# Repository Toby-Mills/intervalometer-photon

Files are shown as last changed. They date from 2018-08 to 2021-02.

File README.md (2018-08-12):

# intervalometer-photon

A Particle project named intervalometer-photon

## Welcome to your project!

Every new Particle project is composed of 3 important elements that you'll see have been created in your project directory for intervalometer-photon.

#### ```/src``` folder:  
This is the source folder that contains the firmware files for your project. It should *not* be renamed. 
Anything that is in this folder when you compile your project will be sent to our compile service and compiled into a firmware binary for the Particle device that you have targeted.

If your application contains multiple files, they should all be included in the `src` folder. If your firmware depends on Particle libraries, those dependencies are specified in the `project.properties` file referenced below.

#### ```.ino``` file:
This file is the firmware that will run as the primary application on your Particle device. It contains a `setup()` and `loop()` function, and can be written in Wiring or C/C++. For more information about using the Particle firmware API to create firmware for your Particle device, refer to the [Firmware Reference](https://docs.particle.io/reference/firmware/) section of the Particle documentation.

#### ```project.properties``` file:  
This is the file that specifies the name and version number of the libraries that your project depends on. Dependencies are added automatically to your `project.properties` file when you add a library to a project using the `particle library add` command in the CLI or add a library in the Desktop IDE.

## Adding additional files to your project

#### Projects with multiple sources
If you would like add additional files to your application, they should be added to the `/src` folder. All files in the `/src` folder will be sent to the Particle Cloud to produce a compiled binary.

#### Projects with external libraries
If your project includes a library that has not been registered in the Particle libraries system, you should create a new folder named `/lib/<libraryname>/src` under `/<project dir>` and add the `.h` and `.cpp` files for your library there. All contents of the `/lib` folder and subfolders will also be sent to the Cloud for compilation.

## Compiling your project

When you're ready to compile your project, make sure you have the correct Particle device target selected and run `particle compile <platform>` in the CLI or click the Compile button in the Desktop IDE. The following files in your project folder will be sent to the compile service:

- Everything in the `/src` folder, including your `.ino` application file
- The `project.properties` file for your project
- Any libraries stored under `lib/<libraryname>/src`

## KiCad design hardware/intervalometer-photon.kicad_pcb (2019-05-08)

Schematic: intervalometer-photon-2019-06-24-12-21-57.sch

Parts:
D1: LED; LED_D5.0mm
J3: Conn_01x02; TerminalBlock_bornier-2_P5.08mm
R1: R; R_Axial_DIN0207_L6.3mm_D2.5mm_P7.62mm_Horizontal
SW1: SW_DIP_x01; TerminalBlock_bornier-2_P5.08mm
U1: LTV-827; DIP-8_W7.62mm
U2: Photon; photon_tht

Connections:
3V3: U2.24
GND: D1.1, SW1.1, U2.21
unnamed: D1.2, U1.2
unnamed: J3.1, U1.8
unnamed: J3.2, U1.7
unnamed: R1.1, U1.1
OPTO: R1.2, U2.14
START: SW1.2, U2.19

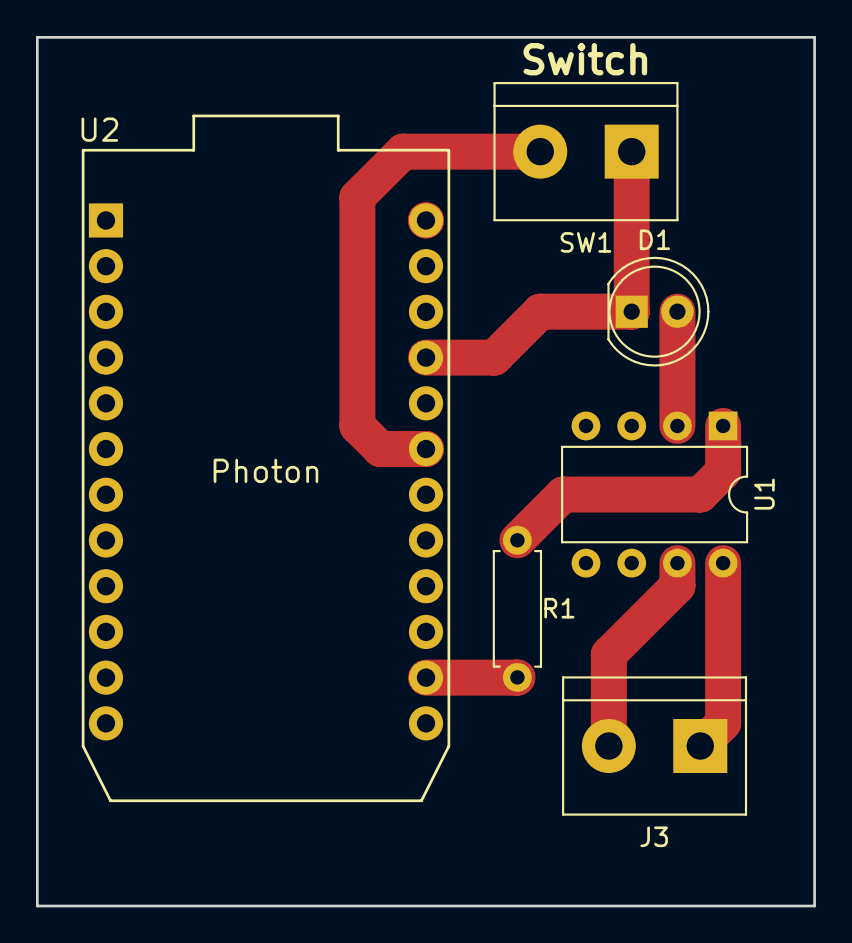
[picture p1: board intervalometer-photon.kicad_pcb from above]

Board: 2 copper layers, 43.2 x 48.3 mm, 6 parts (0 on the bottom side), 7 nets.

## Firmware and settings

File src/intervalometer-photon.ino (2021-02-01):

#include "config.h" //add your own config.h with: char const blynkToken[] = "your-blynk-token-here";
#include "blynk.h"
//--------------------------------------------------------------
// System Configuration
//--------------------------------------------------------------
SYSTEM_THREAD(ENABLED); //enables system functions to happen in a separate thread from the application setup and loop
//this includes connecting to the network and the cloud

//--------------------------------------------------------------
// Pins
//--------------------------------------------------------------
int shutterPin = D1;
int LEDPin = D7;
int switchPin = D6;

//--------------------------------------------------------------
// Blynk Pins
//--------------------------------------------------------------
int blynkPinMessage = 0;
int blynkPinStart = 1;
int blynkPinInterval = 2;
int blynkPinExposure = 3;
int blynkPinMirrorLockup = 4;
int blynkPinBlackFrame = 5;
int blynkPinBracketExposure = 6;

//--------------------------------------------------------------
// User Settings
//--------------------------------------------------------------
int photoIntervalSeconds = 30;
bool mirrorLockupDelay = true;
bool blackFrameEnabled = true;
int exposureLengthMillis = 10000;
int bracketExposureLengthMillis = 0;
bool started = false;

//--------------------------------------------------------------
// Internal Variables
//--------------------------------------------------------------
//enums
enum ExposureBracketShot {UnderExposed, Exposed, OverExposed};
enum PhotoPhase {None = 0, MirrorLockupDelay = 1, MirrorLockupBuffer = 2, Exposure = 3, BlackFrameDelay = 4, Processing = 5};

// internal variables
bool connectedOnce = false;
int debugTimeout = 0;

PhotoPhase currentPhase = None;
int lastPhotoStartTime = 0;
int currentPhaseStartTime = 0;
ExposureBracketShot currentBracketShot = Exposed;
int currentBracketExposureDuration = 0;
int mirrorLockupDuration = 500;
int mirrorLockupBuffer = 1000;
int processingDuration = 300;

char *sourceCode =  "https://github.com/Toby-Mills/intervalometer-photon";

//---------------------------------------------------------------
// Functions
//---------------------------------------------------------------
void start(){
  started = true;
}

void end(){
  started = false;
  setShutter(LOW);
}

void setPhase(PhotoPhase value){
  //char msg [50];
  //sprintf(msg, "set phase %d", value);
  //debugMessage("set phase", msg);
  currentPhase = value;
  currentPhaseStartTime = -1; //indicates that the phase has not started yet
}

bool phaseStarted(){
  return currentPhaseStartTime > -1;
}

void startPhase(){
  currentPhaseStartTime = millis();
}

int phaseElapsedTime(){
  return millis() - currentPhaseStartTime;
}

void setShutter(int value){
  digitalWrite(shutterPin, value);
  digitalWrite(LEDPin, value);
}

bool debugging(){
  return millis() < debugTimeout;
}

int startDebugging(String duration){
  debugTimeout = millis() + duration.toFloat();
  debugMessage("DebugStart","");
  return duration.toFloat();
}

bool userMessage(String message){
  return Particle.publish("message", message);
  Blynk.virtualWrite(0, message);
}

bool debugMessage(String eventName, String data){
  if (debugging()){
    return Particle.publish(eventName, data);
  }
}

//--------------------------------------------------------------
// Setup
//--------------------------------------------------------------

// setup() runs once, when the device is first turned on.
void setup() {
  // Put initialization like pinMode and begin functions here.
  pinMode(shutterPin, OUTPUT);
  pinMode(LEDPin, OUTPUT);
  pinMode(switchPin, INPUT_PULLDOWN);
  
  Particle.variable("sourceCode", sourceCode, STRING);
  Particle.variable("interval", photoIntervalSeconds);
  Particle.variable("lockup", mirrorLockupDelay);
  Particle.variable("blackFrame", blackFrameEnabled);
  Particle.variable("exposure", exposureLengthMillis);
  Particle.variable("bracket", bracketExposureLengthMillis);
  Particle.variable("phaseStart", currentPhaseStartTime);
  Particle.variable("phase", currentPhase);
  Particle.variable("lastPhoto", lastPhotoStartTime);
  Particle.variable("phase", currentPhase);
  Particle.function("startDebug", startDebugging);

  Blynk.begin(blynkToken); //Create connection to Blynk Cloud
  updateBlynkPins(); //update Blynk variables
}

//--------------------------------------------------------------
// Loop
//--------------------------------------------------------------

// loop() runs over and over again, as quickly as it can execute.
void loop() {
  Blynk.run(); //read / write Blynk pins

  //if(digitalRead(switchPin) == HIGH){
  //  start();
  //}else{
  //  end();
  //}

  if(started){
    switch(currentPhase){
      case None:
        if(millis() - lastPhotoStartTime >= photoIntervalSeconds * 1000){
          lastPhotoStartTime = millis();
          if (bracketExposureLengthMillis > 0){
            currentBracketShot = UnderExposed;
          }
          setPhase(MirrorLockupDelay);
        }
        break;
      case MirrorLockupDelay:
        if (mirrorLockupDelay){
          if (phaseStarted()){
            if (phaseElapsedTime() >= mirrorLockupDuration){
              setShutter(LOW);
              setPhase(MirrorLockupBuffer);
            }
          }else{
              startPhase();
              setShutter(HIGH);
          }
        }else{
          setPhase(Exposure);
        }
        break;

      case MirrorLockupBuffer:
          if (mirrorLockupDuration > 0){
            if (phaseStarted()){
              if (phaseElapsedTime() >= mirrorLockupBuffer){
                setPhase(Exposure);
              }
            }else{
              startPhase();
            }
          }else{
            setPhase(Exposure);
          }
        break;

      case Exposure:
        if (phaseStarted()){
          if (phaseElapsedTime() >= currentBracketExposureDuration){
            setShutter(LOW);
            setPhase(BlackFrameDelay);
          }
        }else{
          startPhase();
          switch (currentBracketShot) {
            case UnderExposed:
              currentBracketExposureDuration = exposureLengthMillis - bracketExposureLengthMillis;
              break;
            case Exposed:
              currentBracketExposureDuration = exposureLengthMillis;
              break;
            case OverExposed:
              currentBracketExposureDuration = exposureLengthMillis + bracketExposureLengthMillis;
              break;
          }
          setShutter(HIGH);
        }
        break;

      case BlackFrameDelay:
        if (blackFrameEnabled){
          if (phaseStarted()){
            if (phaseElapsedTime() >= currentBracketExposureDuration){
              setPhase(Processing);
            }
          }else{
            startPhase();
          }
        }else{
          setPhase(Processing);
        }
        break;

      case Processing:
        if (phaseStarted()){
          if (phaseElapsedTime() >= processingDuration){
            if (bracketExposureLengthMillis == 0){
              setPhase(None);
            }else{
              switch(currentBracketShot){
                case UnderExposed:
                  currentBracketShot = Exposed;
                  setPhase(MirrorLockupDelay);
                  break;
                case Exposed:
                  currentBracketShot = OverExposed;
                  setPhase(MirrorLockupDelay);
                  break;
                case OverExposed:
                  setPhase(None);
                  break;
              }
            }
          }
        }else{
          startPhase();
        }
        break;
    }
  }
}

//--------------------------------------------------------------
// Blynk methods
//--------------------------------------------------------------

BLYNK_WRITE(V1)
{
  int pinValue = param.asInt();
  char value[] = "";
  sprintf(value, "%d", pinValue);
  debugMessage("BlynkSetStart", value);
  if (pinValue == 1){start();};
  if (pinValue == 0){end();};
}
BLYNK_WRITE(V2)
{
  int pinValue = param.asInt();
  char value[] = "";
  sprintf(value, "%d", pinValue);
  debugMessage("BlynkSetInterval", value);
  photoIntervalSeconds = pinValue;
}
BLYNK_WRITE(V3)
{
  float pinValue = param.asFloat();
  char value[] = "";
  sprintf(value,"%f", pinValue);
  debugMessage("BlynkSetExposure", value);
  exposureLengthMillis = pinValue * 1000;
}
BLYNK_WRITE(V4)
{
  int pinValue = param.asInt();
  char value[] = "";
  sprintf(value, "%d", pinValue);
  debugMessage("BlynkSetLockup", value);
  mirrorLockupDelay = (pinValue == 1);
}
BLYNK_WRITE(V5)
{
  int pinValue = param.asInt();
  char value[] = "";
  sprintf(value, "%d", pinValue);
  debugMessage("BlynkSetBlackFrame", value);
  blackFrameEnabled = (pinValue == 1);
}
BLYNK_WRITE(V6)
{
  float pinValue = param.asFloat();
  char value[] = "";
  sprintf(value,"%f", pinValue);
  debugMessage("BlynkSetBracket", value);
  bracketExposureLengthMillis = pinValue * 1000;
}

void updateBlynkPins(){
  int blynkPinInterval = 2;
  if(started){
    Blynk.virtualWrite(blynkPinStart, 1);
  }else{
    Blynk.virtualWrite(blynkPinStart,0);
  }
  Blynk.virtualWrite(blynkPinInterval, photoIntervalSeconds);
  Blynk.virtualWrite(blynkPinExposure, exposureLengthMillis / 1000);
  Blynk.virtualWrite(blynkPinMirrorLockup, (mirrorLockupDelay == true));
  Blynk.virtualWrite(blynkPinBlackFrame, (blackFrameEnabled == true));
  Blynk.virtualWrite(blynkPinBracketExposure, bracketExposureLengthMillis / 1000);
}

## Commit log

2018-08-15 Initial hardware design work
    [intervalometer-photon.kicad_pcb, intervalometer-photon.sch]
2018-08-16 bug fixes & syntax
    [intervalometer-photon.ino]
2018-08-16 Bug fix checking last photo time
    [intervalometer-photon.ino]
2018-08-17 Enabled SYSTEM_THREAD to allow network connection in separate thread
2018-08-17 Fixed compile errors for cloud debugging function
    [intervalometer-photon.ino]
2018-08-17 Moved functions up to avoid scope problems
    [intervalometer-photon.ino]
2018-08-20 Added support for switch to start / end activity
    [intervalometer-photon.kicad_pcb, intervalometer-photon.sch]
2018-10-13 Changed switch to use Pin D6, with buit in pull down resistor
2019-05-08 updated hardware schematics
    [intervalometer-photon.kicad_pcb]
2021-01-28 updated firmware to 2.0.1
    [intervalometer-photon-2019-06-24-12-21-57.sch]
